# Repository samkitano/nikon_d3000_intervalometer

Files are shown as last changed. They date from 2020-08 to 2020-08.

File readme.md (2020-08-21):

## NIKON D3000 INTERVALOMETER

A home made intervalometer for Nikon D3000 photo cameras, built around an Arduino Nano board.

## SUMMARY

Intervalometers are the most useful instruments for time-lapse photography, particularly if your camera 
does not have a built-in one, and you don't want to mess around with the proprietary firmware. 
They are also relatively expensive. So, given my late interest in astro-photography, 
as a hobbyist, I've decided to give it a try and build a budget one. This one is specific for the Nikon D3000 camera.
I have NO IDEA if it works with other models/brands. So, please, do not ask. I really don't know.
  
Although the D3000 does not have a port to connect any sort of remote operation device, fortunately it does 
have an IR sensor, located right under the shutter button, which is meant to be used with a remote control. Given it's 
location (camera front), one can only guess it's main purpose is probably for "selfies". We can definitely take 
advantage of that sensor.

## DESCRIPTION

This project is meant to be cheap, simple, and effective, so we can set up:

- the number of shots we want to take
- the time interval between the shots
- a delay time before actually start taking the shots.

It uses 3 simple press buttons:

- one to browse between set up menus (long click to exit main screen, short click to browse between screens)
- one to increase values (short click slow, long click fast)
- one to decrease values (short click slow, long click fast)

And that's it.

Selected values are shown on main screen. Short click and it starts the shooting sequence.

A countdown based on the provided delay time (if any), will then show up, along with an audible signal which 
will become faster as the shooting sequence approaches. The screen will then show which picture # is taking, 
and will go back to the main screen when finished.

## LIMITATIONS 

- max values in the source code can be changed. 
They are in place mostly because of the limited space on the OLED display. 
Also because I don't think I will ever need something bigger.
Feel free to make any code (or hardware) changes you'd like to suit your own needs.

- You need to set your camera up in advance, in order to receive remote signals. 
Please notice that the **MAX TIME** this function 
will be enabled is **15 min**. And you must also set this time up, in your camera. 
After this period, the camera will go 
back to "normal" mode (click to shoot). Nothing we can do about this one, as far as I know :(

## COMPONENTS

- 1 x Arduino "nano"
- 3 x 10K&Omega; pull-down resistors (brown black orange) 250 mw 5%
- 1 x 220&Omega; current limiting resistor (red red brown) 250 mw 5%
- 3 x temporary press buttons
- 1 x piezoelectric buzzer (optional)
- 1 x OLED display 128X64 I2C 0.96"
- 1 x Infrared **emitting** LED in the 940mn range

## ACKNOWLEDGMENT

Shout out to **Aswan Korula** who took the time and effort to analise an actual 
remote control IR signal with his own instruments.
Since I do not own an oscilloscope, or any sort of signal analyzer for that matter, 
it would have been impossible for me to finish this project without his involuntary contribution, 
so BIG THANKS, mate!

Why not visit Aswan's blog, it has some interesting articles:

[Blog](https://bayesianadventures.wordpress.com)

[Remote Hack article](https://bayesianadventures.wordpress.com/2013/08/09/nikon-ml-l3-ir-remote-hack/)

## LICENSE

Intervalometer source code: [MIT license](https://opensource.org/licenses/MIT)

The **OneButton** library: [BSD](http://www.mathertel.de/License.aspx)

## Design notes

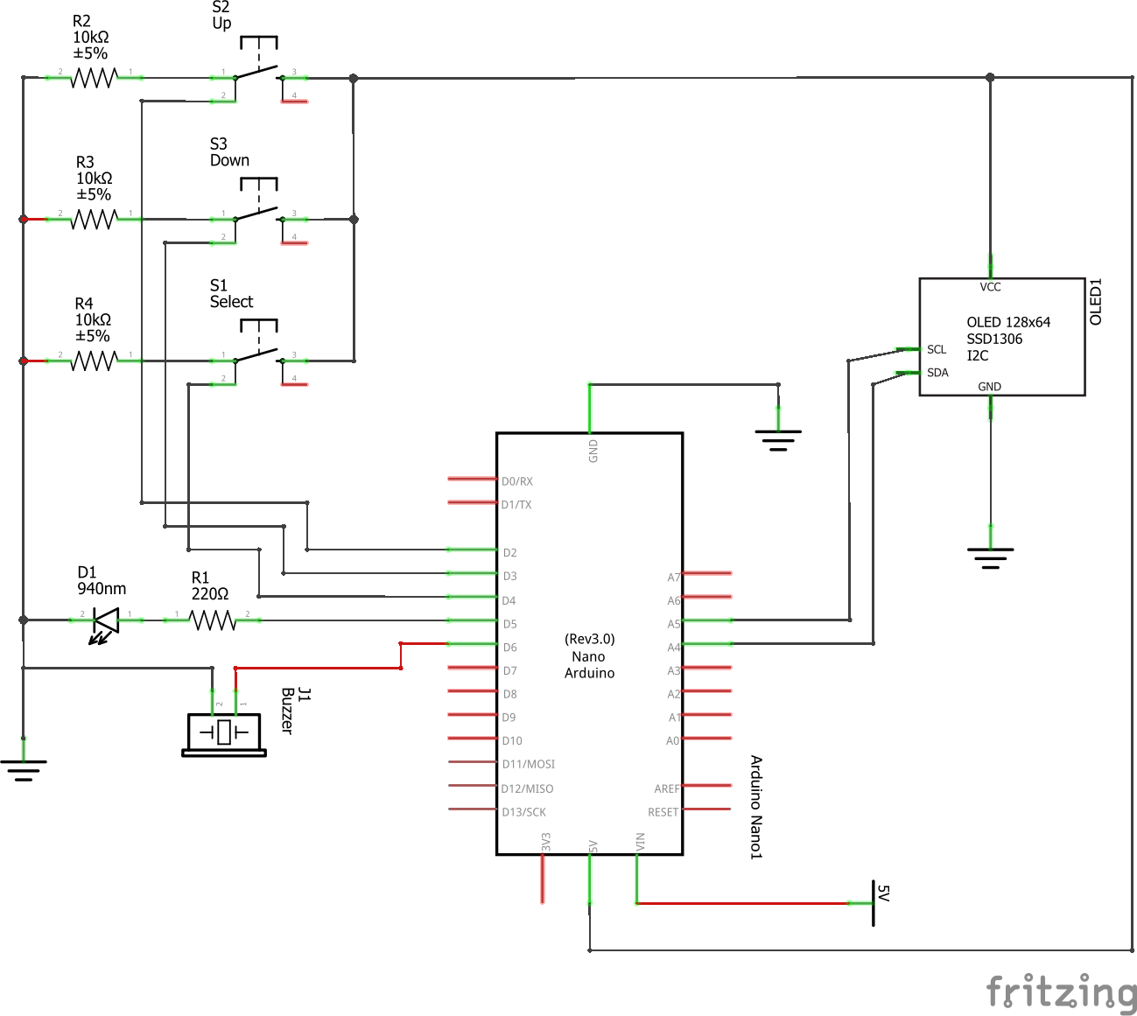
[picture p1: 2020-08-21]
docs/nikon_d3000_intervalometer_schematics.png

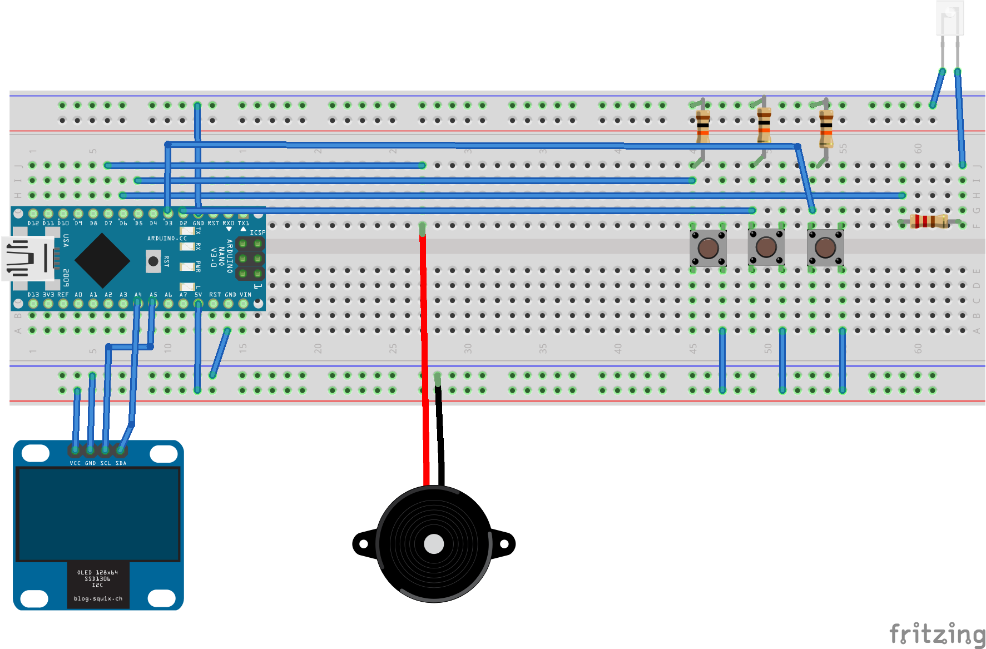
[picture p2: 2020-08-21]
docs/nikon_d3000_intervalometer_breadboard.png

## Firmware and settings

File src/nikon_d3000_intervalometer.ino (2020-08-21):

/**
 * nikon_d3000_intervalometer.ino
 * A simple budget intervalometer for the Nikon D3000 camera
 * built for the Arduino Nano board.
 * Copyright (c) by Sam Kitano 21.08.2020
 * This work is licensed under a MIT style license. See LICENSE for more info.
 */

#include <SPI.h>
#include <Wire.h>
#include "OneButton.h"
#include <Adafruit_GFX.h>
#include <Adafruit_SSD1306.h>

// OLED DISPLAY (SSD1306) DEFS
#define SCREEN_WIDTH 128 // OLED display width, in pixels
#define SCREEN_HEIGHT 64 // OLED display height, in pixels

// PINOUT
#define OLED_RESET -1 // Reset pin # (or -1 if sharing Arduino reset pin)
#define UP_BTN_PIN  2 // Up button
#define DN_BTN_PIN  3 // Down button
#define SEL_BTN_PIN 4 // Selection button
#define IR_PIN      5 // IR LED
#define BUZZ_PIN    6 // Buzzer

// GLOBAL VARS
boolean buttonActive    = false;
boolean longPressActive = false;

unsigned long buttonTimer    = 0;
unsigned long longPressTime  = 500;
unsigned long shortPressTime = 10;

unsigned int shots    =  5; // Shots to take. Minimum is 1
unsigned int interval =  1; // Interval between shots
unsigned int wait     = 10; // Default delay before start taking shots (seconds)
unsigned int dCycle   =  0; // IR Duty cycle
unsigned int page     =  1; // Menu page

// GLOBAL CONSTANTS
unsigned const int steps       =    5; // Steps to fast increase/decrease values
unsigned const int maxWait     =   60; // Max allowed time to delay photoshoot (seconds)
unsigned const int maxShots    =  999; // Max allowed shots
unsigned const int maxInterval = 3600; // Max delay between shots
unsigned const int minWait     =    0; // Min allowed time to delay photoshoot (seconds)
unsigned const int minShots    =    1; // Min allowed shots
unsigned const int minInterval =    1; // Min allowed delay between shots

// CLASS INSTANTIATIONS
Adafruit_SSD1306 display(SCREEN_WIDTH, SCREEN_HEIGHT, &Wire, OLED_RESET);
OneButton buttonUP = OneButton(UP_BTN_PIN, LOW, false); 
OneButton buttonDN = OneButton(DN_BTN_PIN, LOW, false);

/**
 * App setup
 *
 * @return void
 */
void setup() {
  // INIT PINS
  pinMode(IR_PIN, OUTPUT);
  pinMode(SEL_BTN_PIN, INPUT);
  pinMode(BUZZ_PIN, OUTPUT);

  // INIT DISPLAY
  display.begin(SSD1306_SWITCHCAPVCC, 0x3C); // My OLED is actually set for 0x3C, not Adafruit's 0x3D
  display.clearDisplay();
  display.setTextSize(2);
  display.setTextColor(SSD1306_WHITE);
  display.cp437(true); // Use full 256 char 'Code Page 437' font

  // INIT BUTTONS
  buttonUP.attachClick(goUp);
  buttonUP.attachDuringLongPress(goUpFast);
  buttonDN.attachClick(goDown);
  buttonDN.attachDuringLongPress(goDownFast);
  
  showHome();
  buzz();
}


/**
 * Format seconds as 0h00m00s
 *
 * @return String
 */
String intervalTime() {
	unsigned int hour = 0;
	unsigned int min = 0;
	unsigned int sec = 0;
  unsigned int time = interval;
  char h = 'h';
  char m = 'm';
  char s = 's';
  String res1, res2;
  
  if (time < 61) {
    res1 = time;
    return res1 + s;
  }

  if (time > 60 && time < 3600) {
    time = time%3600;
    min = time/60;
    time = time%60;
    sec = time;
    res1 = min;
    res2 = sec;

    if (res2.length() == 1) res2 = '0' + res2;

    return res1 + m + res2 + s;
  }

  return "1h0m0s";
}

/**
 * Sound a bleeping alarm for 1 second
 *
 * @return void
 */
void alarm() {
  unsigned int timer = 1000;
  
  while (timer > 0) {
    tone(BUZZ_PIN, 4000);
    delay(50);
    noTone(BUZZ_PIN);
    delay(50);
    timer = timer - 100;
  }
}

/**
 * Sound a buzzer sound for 250 miliseconds
 *
 * @return void
 */
void buzz() {
  tone(BUZZ_PIN, 4000);
  delay(250);
  noTone(BUZZ_PIN);
}

/**
 * Increase current menu page parameter
 * Possible variables: shots, interval, wait
 *
 * @return void
 */
void goUp() {
  switch (page) {
    case 2:
      shots < maxShots && shots++;
      break;
    case 3:
      interval < maxInterval && interval++;
      break;
    case 4:
      wait < maxWait && wait++;
      break;
    default:
      break;
  }

  showPage();
}

/**
 * Fast increase current menu page parameter
 * Possible variables: shots, interval, wait
 *
 * @return void
 */
void goUpFast() {
  switch (page) {
    case 2:
      shots = shots + steps;
      if (shots > maxShots) shots = maxShots;
      break;
    case 3:
      interval = interval + steps;
      if (interval > maxInterval) interval = maxInterval;
      break;
    case 4:
      wait = wait + steps;
      if (wait > maxWait) wait = maxWait;
      break;
    default:
      break;
  }

  showPage();
}

/**
 * Decrease current menu page parameter
 * Possible variables: shots, interval, wait
 *
 * @return void
 */
void goDown() {
  switch (page) {
    case 2:
      shots > minShots && shots--;
      break;
    case 3:
      interval > minInterval && interval--;
      break;
    case 4:
      wait > minWait && wait--;
      break;
    default:
      break;
  }

  showPage();
}

/**
 * Fast decrease current menu page parameter
 * Possible variables: shots, interval, wait
 *
 * @return void
 */
void goDownFast() {
  switch (page) {
    case 2:
      shots = shots - steps;
      if (shots < minShots || shots > maxShots) shots = minShots;
      break;
    case 3:
      interval = interval - steps;
      if (interval < minInterval || interval > maxInterval) interval = minInterval;
      break;
    case 4:
      wait = wait - steps;
      if (wait < minWait || wait > maxWait) wait = minWait;
      break;
    default:
      break;
  }

  showPage();
}

/**
 * Generates the modulating signal and pulses
 * Original code and IR signal hack by Aswan Korula
 * https://bayesianadventures.wordpress.com/2013/08/09/nikon-ml-l3-ir-remote-hack/
 *
 * @param int dCycle
 * @return void
 */
void sendPulse(int dCycle) {
  int iters = dCycle / 23.6;

  for(int i = 0; i <= iters; i++) {
    digitalWrite(IR_PIN, HIGH);
    delayMicroseconds(11);
    digitalWrite(IR_PIN, LOW);
    delayMicroseconds(5);
  }
}

/**
 * Generates a full command signal by repeatedly calling SendPulse()
 * Original code and IR signal hack by Aswan Korula
 * https://bayesianadventures.wordpress.com/2013/08/09/nikon-ml-l3-ir-remote-hack/
 *
 * @return void
 */
void sendSequence() {
  for(int i = 0; i < 2; i++) {
    sendPulse(2000);
    delay(27);
    delayMicroseconds(800);
    sendPulse(500);
    delayMicroseconds(1500);
    sendPulse(500);
    delayMicroseconds(3500);
    sendPulse(500);
    
    if(i < 1) {
      delay(63);
    }
   }
}

/**
 * Commonly repeated display tasks
 *
 * @return void
 */
void setDisplay() {
  display.clearDisplay();
  display.setCursor(0, 0);
  display.setTextSize(2);
}

/**
 * Present the MAIN page on OLED DISPLAY
 *
 * @return void
 */
void showHome() {
  setDisplay();
  display.println("TAKE SHOTS");
  display.print("Shots:");
  display.println(shots);
  display.print("Del:");

  if (shots == 1) {
    display.println("--");
  } else {
    display.println(intervalTime());
  }

  display.print("Wait:");

  if (wait == 0) {
    display.println("--");
  } else {
    display.print(wait);
    display.println("s");
  }

  display.display();
}

/**
 * Present the SHOTS page on OLED DISPLAY
 *
 * @return void
 */
void showShots() {
  setDisplay();
  display.println("SHOTS:");
  display.println();
  display.setTextSize(3);
  display.println(shots);
  display.display();
}

/**
 * Present the INTERVAL page on OLED DISPLAY
 *
 * @return void
 */
void showInterval() {
  setDisplay();
  display.println("DELAY:");
  display.println();
  display.setTextSize(3);
  display.print(intervalTime());
  display.display();
}

/**
 * Present the DELAY page on OLED DISPLAY
 *
 * @return void
 */
void showWait() {
  setDisplay();
  display.println("WAIT:");
  display.println();
  display.setTextSize(3);
  display.print(wait);
  display.println("s");
  display.display();
}

/**
 * Select and show the current page
 *
 * @return void
 */
void showPage() {
  switch (page) {
    case 1:
      showHome();
      break;
    case 2:
      showShots();
      break;
    case 3:
      showInterval();
      break;
    case 4:
      showWait();
      break;
    default:
      page = 1;
      showHome();
  }
}

/**
 * Countdown before start taking shots
 *
 * @return void
 */
void countDown() {
  unsigned int count = wait;

  if (!wait) return;

  display.setTextSize(5);

  while (count > 0) {
    display.clearDisplay();
    display.setCursor(0, 20);
    display.print(count);
    display.display();

    if (count == 1) {
      alarm();
    } else {
      buzz();
      delay(750);
    }
    
    count--;
  }
}

/**
 * Start shooting sequence
 *
 * @return void
 */
void shoot() {
  countDown();

  for(int i = 1; i <= shots; i++) {
    setDisplay();
    display.println("SHOOTING");
    display.println();
    display.setTextSize(3);
    display.print(i);
    display.print("/");
    display.println(shots);
    display.display();

    sendSequence();
    if (interval > 0) delay(interval * 1000);
  }

  page = 1;
  showHome();
}

/**
 * App loop
 *
 * @return void
 */
void loop() {
  unsigned static long dt;

  buttonUP.tick();
  buttonDN.tick();

  if (digitalRead(SEL_BTN_PIN) == HIGH) {
    if (buttonActive == false) {
			buttonActive = true;
			buttonTimer = millis();
		}

		if ((millis() - buttonTimer > longPressTime) && (longPressActive == false)) {
			longPressActive = true;
      if (page == 1) {
        page++;
      } else {
        page = 1;
      }
      showPage();
		}
	} else {
		if (buttonActive == true) {
			if (longPressActive == true) {
				longPressActive = false;
			} else {
        dt = millis() - buttonTimer;
        if ((dt < longPressTime && dt > shortPressTime) && (longPressActive == false)) {
          if (page == 1) {
            shoot();
          } else {
            page++;
            showPage();
          }
        }
			}
			buttonActive = false;
		}
	}
}
